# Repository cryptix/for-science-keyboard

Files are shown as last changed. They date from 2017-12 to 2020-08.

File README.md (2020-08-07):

*For Science* is a 46 key ortholinear split keyboard PCB with a 3 key thumb cluster.

The goal of this project is to build a usable split keyboard with a PCB case
within the 100x100mm cheap PCB size limit offered by some PCB manufacturers.
Designed to be easy to build,
it only supports serial communication over a TRRS cable and no LEDs.
The PCB is reversible,
meaning that you need two of the same PCB to create a full keyboard.

Final assembled keyboard

PCB render from KiCad

PCBs in white and green

# Bill of Materials (BOM)

* 2 PCBs
* 46 MX compatible switches.
* 46 1n4148 diodes.
* 2 Pro Micro controllers.
* 2 PJ320D 3.5mm TRRS jacks.
* TRRS cable and micro USB cable.
* 2 plate PCBs and 2 base PCBs.
* 8 2M standoffs
* 16 2M screws
* 46 MX compatible key caps.

# Ordering PCBs

PCBs can be manufactured by a variety of online PCB fabricators.
Some have special offers for PCBs under 100mm square,
so shop around.
You can use [PCBShopper](https://pcbshopper.com/) to search for the best price.

The 3 ZIP files in the */gerber* directory contain the Gerber files your fabricator will need to make:

* main PCB [for-science-pcb.zip](
  https://github.com/peej/for-science-keyboard/blob/master/gerber/for-science-pcb.zip)
* plate [for-science-plate.zip](
  https://github.com/peej/for-science-keyboard/blob/master/gerber/for-science-plate.zip)
* base PCB [for-science-base.zip](
  https://github.com/peej/for-science-keyboard/blob/master/gerber/for-science-base.zip)

When uploading the Gerber ZIP files,
use the default PCB settings.
The plate PCB thickness should be 1.6mm for the switches to snap into the plate securely.

# Construction

* Solder the diodes onto the underside of each PCB
* Solder on the Pro Micro headers (or a 24 pin DIP socket) onto the underside of each PCB.
  Do not solder on the Pro Micros yet
* Solder the PJ320D TRRS sockets onto the underside of each PCB.
  These are SMD components rather than through-hole,
  so as not to interfere with the switch locations
* Insert the switches into the plate and then into the top of the PCBs.
  Insert all the switches and ensure that the pins of each switch
  are correctly coming through the board and are not bent under the PCB
* Solder all the switch pins
* Solder on the Pro Micros.
  Ensure that you get them the correct way around
  and with the correct side up.
  The chip side should be face down on the left hand PCB
  and face up on the right hand PCB
* Attach the standoffs to the plate PCB with the screws
* Attach the base to the standoffs
* Connect the halves together with the TRRS cable
* Flash both Pro Micros with the firmware,
  see the [QMK documentation](http://qmk.fm/)
  on how to build and flash the firmware

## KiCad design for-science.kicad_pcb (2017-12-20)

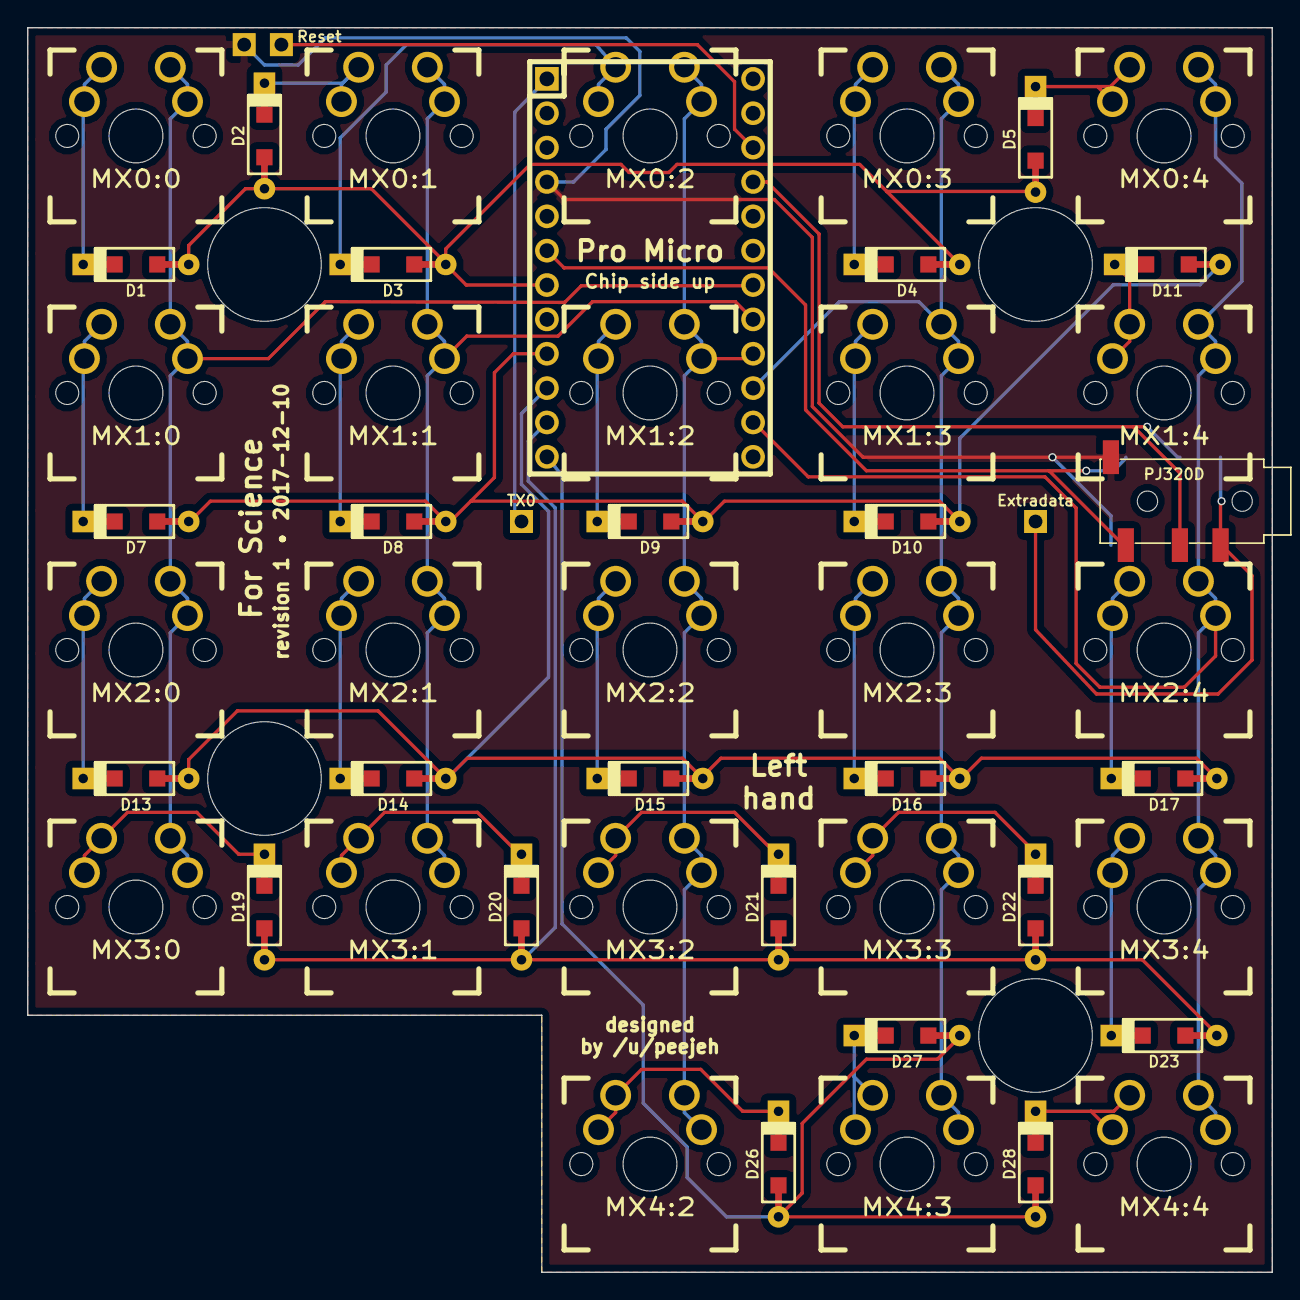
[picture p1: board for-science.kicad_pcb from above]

Board: 2 copper layers, 92.0 x 92.0 mm, 57 parts (1 on the bottom side), 39 nets.

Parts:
D1, D2, D3, D4, D5, D7, D8, D9, D10, D11, D13, D14, D15, D16, D17, D19, D20, D21, D22, D23, D26, D27, D28: DIODE; D_SOD123_axial
EXTRADATA1: Extradata; PIN_1_SQUARE
GROUND1: Ground; PIN_1_SQUARE
J1: TRRS; PJ320D_3.5mm_Jack_SMD
J2: TRRS; PJ320D_3.5mm_Jack_SMD_Flip
M8, M8#2, M8#3, M8#4: MountingHole_8.4mm_M8
MX0:0: MX0:9; MX_DoubleSided
MX0:1: MX0:8; MX_DoubleSided
MX0:2: MX0:7; MX_DoubleSided
MX0:3: MX0:6; MX_DoubleSided
MX0:4: MX0:5; MX_DoubleSided
MX1:0: MX1:9; MX_DoubleSided
MX1:1: MX1:8; MX_DoubleSided
MX1:2, MX1:4: MX1:7; MX_DoubleSided
MX1:3: MX1:6; MX_DoubleSided
MX2:0: MX2:9; MX_DoubleSided
MX2:1: MX2:8; MX_DoubleSided
MX2:2: MX2:7; MX_DoubleSided
MX2:3: MX2:6; MX_DoubleSided
MX2:4: MX2:5; MX_DoubleSided
MX3:0: MX3:9; MX_DoubleSided
MX3:1: MX3:8; MX_DoubleSided
MX3:2: MX3:7; MX_DoubleSided
MX3:3: MX3:6; MX_DoubleSided
MX3:4: MX3:5; MX_DoubleSided
MX4:2: MX4:7; MX_DoubleSided
MX4:3: MX4:6; MX_DoubleSided
MX4:4: MX4:5; MX_DoubleSided
RESET1: Reset; PIN_1_SQUARE
TX0: TX0; PIN_1_SQUARE
U1: ARDUINO_PRO_MICRO

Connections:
/Col0: MX0:0.1, MX1:0.1, MX2:0.1, MX3:0.1, U1.18
/Col1: MX0:1.1, MX1:1.1, MX2:1.1, MX3:1.1, U1.17
/Col2: MX0:2.1, MX1:2.1, MX2:2.1, MX3:2.1, MX4:2.1, U1.16
/Col3: MX0:3.1, MX1:3.1, MX2:3.1, MX3:3.1, MX4:3.1, U1.15
/Col4: MX0:4.1, MX1:4.1, MX2:4.1, MX3:4.1, MX4:4.1, U1.14
/Row0: D1.2, D2.2, D3.2, D4.2, D5.2, U1.7
/Row1: D7.2, D8.2, D9.2, D10.2, D11.2, U1.9
/Row2: D13.2, D14.2, D15.2, D16.2, D17.2, U1.10
/Row3: D19.2, D20.2, D21.2, D22.2, D23.2, U1.11
/Row4: D26.2, D27.2, D28.2, U1.12
GND: GROUND1.1, J1.4, J2.4, U1.4
unnamed: D1.1, MX0:0.2
unnamed: D2.1, MX0:1.2
unnamed: D3.1, MX0:2.2
unnamed: D4.1, MX0:3.2
unnamed: D5.1, MX0:4.2
unnamed: D7.1, MX1:0.2
unnamed: D8.1, MX1:1.2
unnamed: D9.1, MX1:2.2
unnamed: D10.1, MX1:3.2
unnamed: D11.1, MX1:4.2
unnamed: D13.1, MX2:0.2
unnamed: D14.1, MX2:1.2
unnamed: D15.1, MX2:2.2
unnamed: D16.1, MX2:3.2
unnamed: D17.1, MX2:4.2
unnamed: D19.1, MX3:0.2
unnamed: D20.1, MX3:1.2
unnamed: D21.1, MX3:2.2
unnamed: D22.1, MX3:3.2
unnamed: D23.1, MX3:4.2
unnamed: D26.1, MX4:2.2
unnamed: D27.1, MX4:3.2
unnamed: D28.1, MX4:4.2
unnamed: EXTRADATA1.1, J1.3, J2.3
unnamed: J1.1, J2.1, U1.6
unnamed: RESET1.1, U1.22
unnamed: TX0.1, U1.1
VCC: J1.2, J2.2, U1.21

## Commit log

2017-12-20 Add gerber files
    Former-commit-id: ffd29a30d6e1f60fa59137906bac824ee8369ceb
    [base.kicad_pcb, for-science.kicad_pcb, plate.kicad_pcb]
2018-02-06 Add assembled keyboard picture
    Former-commit-id: 4cb12e38262253e15162c06579b20d56226f6bdf
2020-08-31 base: Adds OSEG logo and meta-data
    * Source (fixed, manual value)
    * License (fixed, manual value)
    * Version (placeholder, missing replacement method!)
    * Version-Date (placeholder, missing replacement method!)
    * Manufacturer (fixed, manual value)
    * Manufacturer-Serial-Number (placeholder, filled in by manufacturer)
    * Batch (fixed, manual value)
    [base.kicad_pcb]
2020-09-08 CI: Try to generate Gerbers & co with KiBot
2020-09-09 Update SCH from KiCad v2 to v5
    [for-science.sch]
2020-09-09 CI: KiBot: Unuse non-existent BoM fields [fix]
2021-12-10 fix typos in github actions
    jobs names and output of DRC and ERC were switched

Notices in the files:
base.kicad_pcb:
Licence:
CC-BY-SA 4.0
